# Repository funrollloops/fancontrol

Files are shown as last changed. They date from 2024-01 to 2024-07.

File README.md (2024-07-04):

## Overview
v1 used an arduino nano with a custom PCB on top, but the result was thick and ungainly. v2 uses a pcb with an stm32 integrated on board,
but still expects to use an OLED on a 4-pin carrier board. This does fit inside a Meshlicious alongside a 280mm rad, but it could be more elegant.

v2 includes a USB port, but it's not really used by the firmware. Removing it in v3 might allow for a sleeker design that is easier to put in a case.

### Clearance inside Meshlicious
Total available clearance is 10mm:

* 1.6mm PCB
* 6.5mm for right angle fan header on back
* 6.3mm for the oled display module
    * 1.6mm for the PCB
    * 1.6mm for the display
    * 3.1mm for the JST connector (1.1mm for components w/o connector)

So will need to use a bare oled display and use an FPC connector to save space.
All components will be on the top side of the PCB, which will face towards the
radiator/fan where the fan connectors come out.

## Schematic

See the pcb/ directory. Designed for PCBA via JLCPCB, using only one extended part (the USB-C connector). Costs $20 shipped for 5x.

## Firmware

Install [STM32CubeProgrammer](https://www.st.com/en/development-tools/stm32cubeprog.html) somewhere, and then build and flash with
```
cmake -S. -Bbuild -DCMAKE_BUILD_TYPE=Release -GNinja -DSTM32_CUBE_PROGRAMMER=/path/to/STM32_Programmer_CLI
ninja -Cbuild flash
```

## Design

## Calibration

WIP, will log CPU/GPU/thermistor readings to create a calibration table.  According to the datasheet,
given some inputs the output formula should be:

```py
# Circuit: VCC - R2 - thermistor - GND
#                   ⌞ ADC

VCC = 5
AREF = 3.3
R2 = 33_000

def C(adc):
    """adc is the voltage across the thermistor when it is in series with R2, where 0=0V and 1024=AREF."""
    return 227 - 34.3 * ln(adc)
```

But a lookup table is probably simpler since only ~1C accuracy is needed and there's no FPU anyway.

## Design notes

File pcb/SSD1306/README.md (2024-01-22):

# Source

Copied from [pforrmi/KiCad-SSD1306-128x64](https://github.com/pforrmi/KiCad-SSD1306-128x64) and modified to fit my module, which has VCC on pin 1 and GND on pin 2.

# SSD1306 128x64 for kicad  

Kicad footprints and templates for [SSD1306 128x64px OLED Display*](https://amzn.to/2YUHoEB).



https://www.kicad.org

## SSD1306 as a component

You can use the SSD1306 as a module of a bigger kicad PCB project. 

### for eeschema
`library/SSD1306-128x64_OLED.lib` can be used as a component in your design.

To add it to eeschema:
* Preferences
* Components libraries
* add
* navigate to the `SSD1306-128x64_OLED.lib` file

### for pcbnew

`library/SSD1306.pretty` contains a footprint of the SSD1306 module for your PCB.

To add it to pcbnew:
* Preferences
* Footprint library manager
* Project Specific Libraries
* Append with Wizard
* navigate to `SSD1306.pretty`

### Further information may be found at https://ownsmarthome.de

_The links marked with an asterisk (*) are commission links or advertising._

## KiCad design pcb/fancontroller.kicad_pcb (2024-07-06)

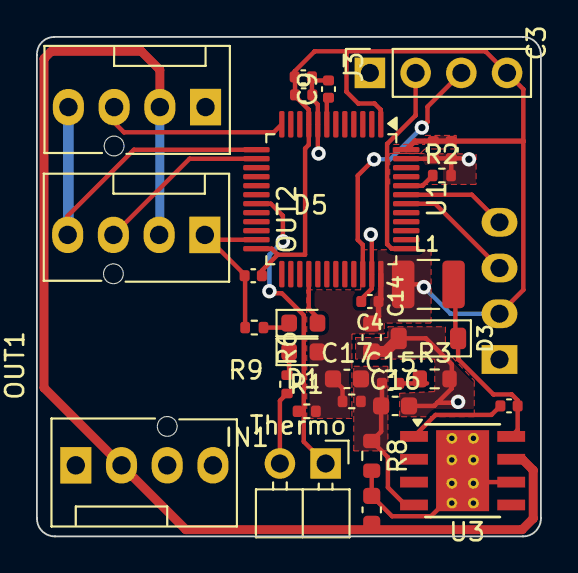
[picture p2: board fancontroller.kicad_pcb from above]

Board: 2 copper layers, 28.0 x 27.8 mm, 32 parts (1 on the bottom side), 20 nets.

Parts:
C1: 4.7uF; C_0402_1005Metric
C2, C3, C4, C15: 100nF; C_0402_1005Metric
C5: 1uF; C_0402_1005Metric
C6, C13: 10nF; C_0402_1005Metric
C9: 100n; C_0402_1005Metric
C12: 10uF; C_0603_1608Metric
C14: 22uF; C_0603_1608Metric
C16: 150pF; C_0603_1608Metric
C17: 1.5nF; C_0603_1608Metric
D1, D5: white; LED_0603_1608Metric
D3: B5819W; D_SOD-123
IN1: FAN_HEADER; FanPinHeader_1x04_P2.54mm_Vertical
J1: Thermo; PinHeader_1x02_P2.54mm_Horizontal
J3: SWD; PinSocket_1x04_P2.54mm_Vertical
L1: 10uH; L_1210_3225Metric
OUT1, OUT2: FAN_HEADER; FanPinHeader_1x04_P2.54mm_Vertical
R1: 33kΩ; R_0402_1005Metric
R2: 5.1kΩ; R_0402_1005Metric
R3: 549Ω; R_0603_1608Metric
R6, R9: 1.5kΩ; R_0402_1005Metric
R7: 10kΩ; R_0402_1005Metric
R8: 5.9kΩ; R_0603_1608Metric
SSD1306: SSD1306; 128x64OLED
U1: STM32F103C8Tx; LQFP-48_7x7mm_P0.5mm
U3: TPS5430DDA; TI_SO-PowerPAD-8_ThermalVias

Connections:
+3.3V: C1.1, C2.1, C3.1, C4.1, C5.1, C6.1, C14.1, C17.1, D1.2 (A), J3.4, L1.2, R1.1, R7.1, SSD1306.2 (VCC), U1.1 (VBAT), U1.9 (VDDA), U1.24 (VDD), U1.36 (VDD), U1.48 (VDD)
+12V: C12.1, IN1.2 (+), OUT1.2 (+), OUT2.2 (+), U3.7 (VIN)
/APP_LED: D5.1 (K), R9.1
/BOOT0: R2.1, U1.44 (BOOT0)
/NRST: C9.1, U1.7 (NRST)
/PFSENSE: C15.1, C16.1, C17.2, R7.2, R8.1, U3.4 (VSENSE)
/PLED_K: D1.1 (K), R6.1
/PWM: OUT1.4 (PWM), OUT2.4 (PWM), U1.13 (PA3)
/SCL: SSD1306.3 (SCL), U1.42 (PB6)
/SDA: SSD1306.4 (SDA), U1.43 (PB7)
/SWCLK: J3.2, U1.37 (PA14)
/SWDIO: J3.3, U1.34 (PA13)
/TACH1: IN1.3 (Tacho), OUT1.3 (Tacho), U1.14 (PA4)
/TACH2: OUT2.3 (Tacho), U1.12 (PA2)
/TEMP: J1.1, R1.2, U1.19 (PB1)
GND: C1.2, C2.2, C3.2, C4.2, C5.2, C6.2, C9.2, C12.2, C14.2, C16.2, D3.2 (A), IN1.1 (-), J1.2, J3.1, OUT1.1 (-), OUT2.1 (-), R2.2, R3.2, R6.2, R8.2, R9.2, SSD1306.1 (GND), U1.8 (VSSA), U1.23 (VSS), U1.35 (VSS), U1.47 (VSS), U3.6 (GND), U3.9 (GNDPAD)
unnamed: C15.2, R3.1
unnamed: C13.2, D3.1 (K), L1.1, U3.8 (PH)
unnamed: D5.2 (A), U1.28 (PB15)
unnamed: C13.1, U3.1 (BOOT)

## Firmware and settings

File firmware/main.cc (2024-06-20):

#include "main.h"

#include <algorithm>
#include <array>
#include <atomic>
#include <charconv>
#include <cstdio>
#include <functional>

#include "adc.h"
#include "adc_to_celsius.h"
#include "gpio.h"
#include "ssd1306.h"
#include "ssd1306_fonts.h"
#include "stm32f1xx_hal.h"
#include "tim.h"
#ifdef SSD1306_USE_SPI
#include "spi.h"
#else
#include "i2c.h"
#endif

enum ADC_MODE {
  ADC_MODE_POLLING,
  ADC_MODE_INTERRUPT,
  ADC_MODE_DMA,
};

static constexpr ADC_MODE kAdcMode = ADC_MODE_POLLING;
static constexpr bool PRIME = false;
uint32_t adc_val;
std::atomic<uint16_t> tach1 = 0;
std::atomic<uint16_t> tach2 = 0;

void set_pwm_pct(uint32_t val) { TIM2->CCR4 = val; }

int thermistor_adc_to_celsius(uint16_t adc) {
  const auto &table = adc_for_celsius;
  return std::distance(std::begin(table),
                       std::lower_bound(std::begin(table), std::end(table), adc,
                                        std::greater{}));
}

void ssd1306_WriteInt(uint16_t num, SSD1306_Font_t font, SSD1306_COLOR color) {
  char str[10];
  auto r = std::to_chars(std::begin(str), std::end(str), num);
  *r.ptr = '\0';
  ssd1306_WriteString(str, font, color);
}

int write_line(int ypos, SSD1306_Font_t font, const char *prefix, uint16_t num,
               const char *suffix) {
  ssd1306_SetCursor(0, ypos);
  ssd1306_WriteString(prefix, font, White);
  ssd1306_WriteInt(num, font, White);
  ssd1306_WriteString(suffix, font, White);
  return ypos + font.height + 2;
}

uint8_t fan_speed(int temp) {
  static constexpr uint8_t MIN_SPEED = 20;
  static constexpr uint8_t MAX_SPEED = 100;
  static constexpr uint8_t MAX_LINEAR_TEMP = 55;
  static constexpr uint8_t MIN_LINEAR_TEMP = 40;
  if constexpr (!PRIME) {
    if (temp > MAX_LINEAR_TEMP) {
      return MAX_SPEED;
    } else if (temp > MIN_LINEAR_TEMP) {  // Linear range.
      return (MAX_SPEED - MIN_SPEED) * (temp - MIN_LINEAR_TEMP) /
                 (MAX_LINEAR_TEMP - MIN_LINEAR_TEMP) +
             MIN_SPEED;
    } else if (temp > 20) {  // 20C = 68F
      return MIN_SPEED;
    } else {
      return MAX_SPEED;  // In case of a bad reading, run at full speed.
    }
  } else {
    static uint8_t ticks = 0;
    static constexpr uint8_t PERIOD = 64;
    uint8_t qq = ticks++ % PERIOD;
    if (qq < PERIOD / 4) {
      return 255;
    } else if (qq > 3 * PERIOD / 4) {
      return 30;
    } else {
      return 255 - (qq - PERIOD / 4) * (255 - 30) / (PERIOD / 2);
    }
  }
}

int main(void) {
  HAL_Init();
  SystemClock_Config();
  MX_GPIO_Init();
  MX_ADC2_Init();
  MX_TIM2_Init();
#ifdef SSD1306_USE_SPI
  MX_SPI1_Init();
#else
  MX_I2C1_Init();
#endif
  ssd1306_Init();

  HAL_TIM_PWM_Start(&htim2, TIM_CHANNEL_4);
  if constexpr (kAdcMode == ADC_MODE_POLLING) {
    HAL_ADC_Start(&hadc2);
  } else if constexpr (kAdcMode == ADC_MODE_INTERRUPT) {
    HAL_ADC_Start_IT(&hadc2);
  } else if constexpr (kAdcMode == ADC_MODE_DMA) {
    HAL_ADC_Start_DMA(&hadc2, &adc_val, 2);
  }
  while (1) {
    tach1 = 0;
    tach2 = 0;
    HAL_Delay(1000);
    uint16_t t1 = tach1;
    uint16_t t2 = tach2;
    // Convert to RPM, two pulses per revolution.
    t1 = t1 * 60 / 2;
    t2 = t2 * 60 / 2;
    const int temp = thermistor_adc_to_celsius(adc_val);
    set_pwm_pct(fan_speed(temp));
    const float ar = adc_val / 4095.0;
    const float r2 = 33.3e3;
    const float r = ar * r2 / (1 - ar);

    if constexpr (kAdcMode == ADC_MODE_POLLING) {
      HAL_ADC_PollForConversion(&hadc2, 1);
      HAL_ADC_ConvCpltCallback(&hadc2);
    }
    ssd1306_Fill(Black);
    if (SSD1306_HEIGHT == 64) {
      ssd1306_SetCursor(0, 4);
      if (temp < 99) ssd1306_WriteChar(' ', Font_16x26, White);
      if (temp < 9) ssd1306_WriteChar(' ', Font_16x26, White);
      ssd1306_WriteInt(temp, Font_16x26, White);
      ssd1306_WriteString("C ", Font_11x18, White);
      ssd1306_WriteInt(std::min<uint16_t>(99, TIM2->CCR4), Font_16x26, White);
      ssd1306_WriteString("%", Font_11x18, White);

      const int rpm_ypos = 62 - 2 * Font_7x10.height;
      int ypos = rpm_ypos;
      ypos = write_line(ypos, Font_7x10, "", t1, "rpm");
      ssd1306_SetCursor(64, rpm_ypos);
      ssd1306_WriteInt(t2, Font_7x10, White);
      ssd1306_WriteString("rpm", Font_7x10, White);
      ypos = write_line(ypos, Font_7x10, "ADC=", adc_val, "  R=");
      ssd1306_WriteInt(r, Font_7x10, White);
      ssd1306_UpdateScreen();
    } else {
      ssd1306_SetCursor(0, 0);
      ssd1306_WriteString("Hello, World!", Font_7x10, White);
    }
  }
  return 0;
}

extern "C" {
void HAL_ADC_ConvCpltCallback(ADC_HandleTypeDef *) {
  adc_val = hadc2.Instance->DR;
}

void ADC_IRQHandler(ADC_HandleTypeDef *hadc) { HAL_ADC_IRQHandler(hadc); }

void HAL_GPIO_EXTI_Callback(uint16_t GPIO_Pin) {
  switch (GPIO_Pin) {
    case TACH1_Pin:
      tach1.fetch_add(1);
      break;
    case TACH2_Pin:
      tach2.fetch_add(1);
      break;
  }
  HAL_GPIO_TogglePin(LED_GPIO_Port, LED_Pin);
}
}

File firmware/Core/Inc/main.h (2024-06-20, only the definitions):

#define OLED_Reset_Pin GPIO_PIN_0
#define OLED_Reset_GPIO_Port GPIOA
#define OLED_DC_Pin GPIO_PIN_1
#define OLED_DC_GPIO_Port GPIOA
#define TACH2_Pin GPIO_PIN_2
#define TACH2_GPIO_Port GPIOA
#define TACH2_EXTI_IRQn EXTI2_IRQn
#define PWM_Pin GPIO_PIN_3
#define PWM_GPIO_Port GPIOA
#define TACH1_Pin GPIO_PIN_4
#define TACH1_GPIO_Port GPIOA
#define TACH1_EXTI_IRQn EXTI4_IRQn
#define OLED_CS_Pin GPIO_PIN_6
#define OLED_CS_GPIO_Port GPIOA
#define POT_LOW_Pin GPIO_PIN_0
#define POT_LOW_GPIO_Port GPIOB
#define TEMP_Pin GPIO_PIN_1
#define TEMP_GPIO_Port GPIOB
#define LED_Pin GPIO_PIN_2
#define LED_GPIO_Port GPIOB
#define POT_HIGH_Pin GPIO_PIN_10
#define POT_HIGH_GPIO_Port GPIOB

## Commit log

2023-12-29 Fan control test scripts
2024-01-22 v1 PCB revision + working firmware
    [fancontroller.kicad_pcb, fancontroller.kicad_sch]
2024-01-24 Delete calibration directory
    Not needed; manually calibrated using my multimeter.
2024-05-17 Rename board=>pcb
    [fancontroller.kicad_pcb, fancontroller.kicad_sch]
2024-06-02 Update to Kicad 8, clean up schematic, add second fan header to schematic
    [fancontroller.kicad_pcb, fancontroller.kicad_sch]
2024-06-02 wip: switch to stm32f103
    [fancontroller.kicad_sch]
2024-06-09 v2: add stm32cubemx config, early draft of pcb layout, update version
    [fancontroller.kicad_pcb, fancontroller.kicad_sch]
2024-06-09 v2: more stm32cubemx, start generating code
2024-06-10 firmware/{stm32cubemx => }
2024-06-10 Finish routing assuming OLED module
    [fancontroller.kicad_pcb, fancontroller.kicad_sch]
2024-06-10 Blink an LED
2024-06-12 Get PWM, ADC, and gpio interrupts working
2024-06-14 v2 firmware: add in display, temp, pwm calculation
2024-06-20 add app led, commit attempts to use 0.91" display
    [fancontroller.kicad_sch]
2024-06-20 Add LED
    [fancontroller.kicad_pcb, fancontroller.kicad_sch]
2024-07-06 Begin rev3: drop USB connector, plan for OLED mounting
    [fancontroller.kicad_pcb, fancontroller.kicad_sch]

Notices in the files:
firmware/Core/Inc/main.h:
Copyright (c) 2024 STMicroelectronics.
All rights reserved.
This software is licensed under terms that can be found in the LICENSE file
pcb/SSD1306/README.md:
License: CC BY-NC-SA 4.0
